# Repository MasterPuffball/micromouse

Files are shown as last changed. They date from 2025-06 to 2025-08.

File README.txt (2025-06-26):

Motor mount has been designed to take a future Pololu Ball Caster with 1/2" metal ball. aka Pololu 953 

https://www.pololu.com/product/953/resources
https://www.digikey.com.au/en/products/detail/pololu/953/10449917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

## Lengths
### Wheel to other Wheel: 83.5mm
### Wheel Width: 6mm
### Axel Length: 89.5mm
### Axel Radius: 44.75mm

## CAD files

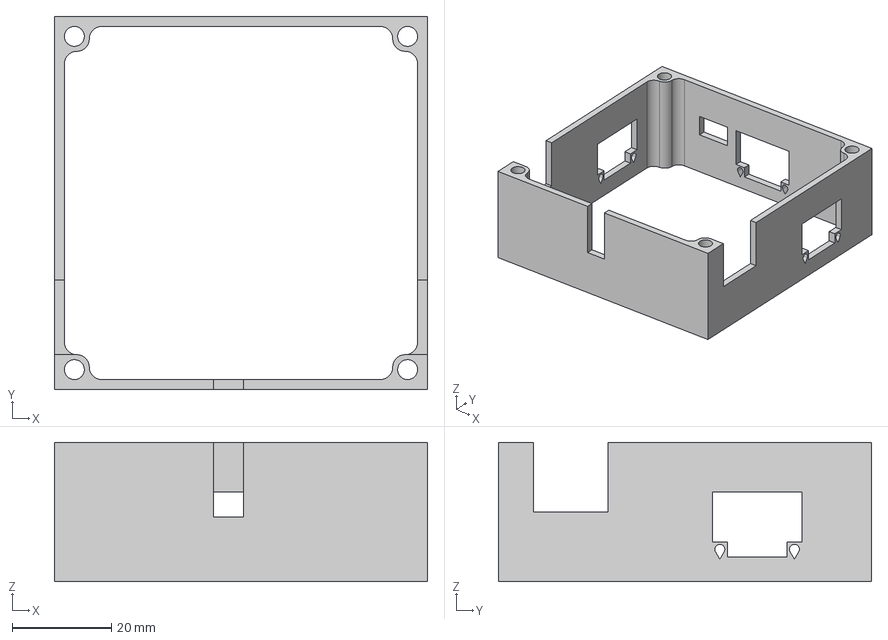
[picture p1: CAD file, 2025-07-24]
mounting/Micromouse Cap.step
75.0 x 75.0 x 28.0 mm

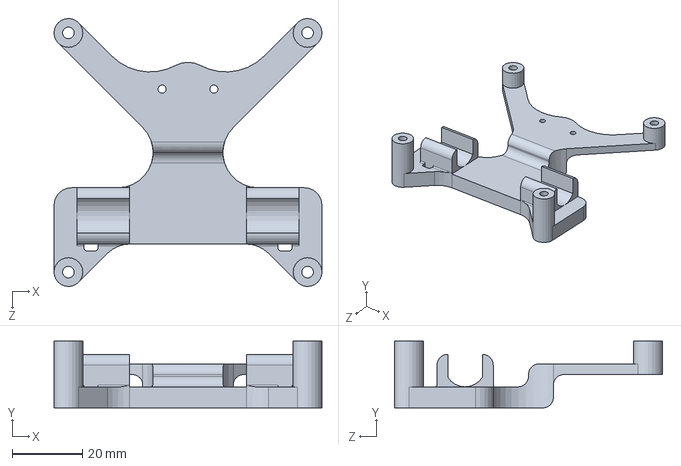
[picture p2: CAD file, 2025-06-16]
mounting/motor_mount.SLDPRT
76.1 x 19.0 x 76.1 mm

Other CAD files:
mounting/Micromouse Cap.SLDPRT
mounting/motor_mount.STL

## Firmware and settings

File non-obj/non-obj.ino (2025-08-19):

#include <SPI.h>
#include <Wire.h>
#include <U8g2lib.h>
#include <Adafruit_GFX.h>

#include "Encoder.hpp"
#include "Motor.hpp"
#include "PIDController.hpp"
#include "Wheel.hpp"
#include "IMU.hpp"
#include "Lidar.hpp"
#include "Map.hpp"
#include "EncoderOdometry.hpp"
#include "Constants.h"
#include "MapRenderer.hpp"

int curTime = 0;
int setCursorFirst = 10;
int setCursorSecond = 7;
float general_speed = 0.45;

struct Robot {
  U8G2_SSD1306_128X64_NONAME_1_HW_I2C display{U8G2_R0, U8X8_PIN_NONE};

  // Maps
  mtrn3100::Map map{};
  mtrn3100::MapRenderer mapRenderer{display, map};

  // Controllers
  static constexpr float KP1 = 2.3;
  static constexpr float KI1 = 0.2;
  static constexpr float KD1 = 0.1;
  mtrn3100::PIDController left_controller{KP1, KI1, KD1};

  static constexpr float KP2 = 2.3;
  static constexpr float KI2 = 0.2;
  static constexpr float KD2 = 0.1;
  mtrn3100::PIDController right_controller{KP2, KI2, KD2};

  // Encoder direction controller
  static constexpr float KP3 = 1.5;
  static constexpr float KI3 = 0.1;
  static constexpr float KD3 = 0.1;
  mtrn3100::PIDController diff_controller{KP3, KI3, KD3};

  // True direction controller
  static constexpr float KP4 = 2.3;
  static constexpr float KI4 = 0.8;
  static constexpr float KD4 = 0.08;
  mtrn3100::PIDController direction_controller{KP4, KI4, KD4, true};

  // Distance Controller
  static constexpr float KP5 = 1.5;
  static constexpr float KI5 = 0.3;
  static constexpr float KD5 = 0.1;
  mtrn3100::PIDController distance_controller{KP5, KI5, KD5};

  // Motors
  static constexpr int MOT2PWM = 9;
  static constexpr int MOT2DIR = 10;
  static constexpr int MOT1PWM = 11;
  static constexpr int MOT1DIR = 12;
  mtrn3100::Motor left_motor{MOT1PWM, MOT1DIR};
  mtrn3100::Motor right_motor{MOT2PWM, MOT2DIR};

  // Encoders
  static constexpr int MOT1ENCA = 2; // PIN 2 is an interupt
  static constexpr int MOT2ENCA = 3;
  static constexpr int MOT1ENCB = 7; // PIN 7 is an interupt
  static constexpr int MOT2ENCB = 8;
  mtrn3100::Encoder left_encoder{MOT1ENCA, MOT1ENCB, 0};
  mtrn3100::Encoder right_encoder{MOT2ENCA, MOT2ENCB, 1};
  mtrn3100::EncoderOdometry odom{&left_encoder, &right_encoder};

  // Wheels
  static constexpr float RIGHT_COEF = 0.91;
  static constexpr float LEFT_COEF = 0.95;
  mtrn3100::Wheel left_wheel{&left_motor, &left_encoder};
  mtrn3100::Wheel right_wheel{&right_motor, &right_encoder};

  // IMU
  mtrn3100::IMU imu{};

  // Lidars
  static constexpr int leftSensorPin = A0;
  static constexpr int frontSensorPin = A1;
  static constexpr int rightSensorPin = A2;
  static constexpr int leftSensorAddress = 0x54;
  static constexpr int frontSensorAddress = 0x56;
  static constexpr int rightSensorAddress = 0x58;
  mtrn3100::Lidar left_lidar{leftSensorPin, leftSensorAddress};
  mtrn3100::Lidar front_lidar{frontSensorPin, frontSensorAddress};
  mtrn3100::Lidar right_lidar{rightSensorPin, rightSensorAddress};

  int robotX = STARTING_X;
  int robotY = STARTING_Y;
  int robotOrientation = STARTING_ORIENTATION;

  Robot() {
  }

  void begin() {
    Serial.println("Beginning Robot");

    initScreen();
    Serial.println("Display Setup Complete");
    drawString("Display Setup Complete");

    delay(50);
  
    imu.begin();
    Serial.println("IMU Setup Complete");
    drawString("IMU Setup Complete");

    odom.begin();

    delay(50);

    initWheels();
    Serial.println("Wheel Setup Complete");
    drawString("Wheel Setup Complete");
        
    delay(50);
    Serial.println("Finished Setup");
    drawString("Finished Setup");
  }
  
  void loop() {
    // moveForwardOneCell();
    
    // display.firstPage();
    // do {
    //   mapRenderer.drawCompletion();
    // } while (display.nextPage());

    exploreMap();
    mapRenderer.drawMap();
	  while (true) {}

    // turnToAngle(0,0.5);
    // maintainDistance(100, 0.5); 
    // turnLeft90(); 
    // executeMovementString("frflflfrf");
    // executeMovement('l');
    // turnToAngle(90,0.4);
    // maintainDistance(100, 0.5);
    // direction_controller.tune(KP4, KI4, i);
    // Serial.println(imu.getDirection());
    // getLeftDist();
    // getFrontDist();
    // getRightDist();
    // turnRight90();
    // testPrintLines();
    
    // drawTelemetry(direction_controller);
    // executeMovementString("lfrfflfr");
    // executeMovementString("ffllfrfr");
    // turnToAngle(-90, 0.3);
    // executeMovementString("r");

  }

  void initScreen() {
    display.begin();
    display.clearBuffer(); // Clear the internal memory
    display.setFont(u8g2_font_4x6_tr); // Choose a suitable font
    display.setCursor(setCursorFirst, setCursorSecond);
    display.print("Staring!!!"); // Write a string to the display
    display.sendBuffer(); // Transfer internal memory to the display
  }

  void initWheels() {
    left_motor.flip();
    // right_motor.flip();
    // left_encoder.flip();
    right_encoder.flip();
  }

  void drawTelemetry(mtrn3100::PIDController controller) {
    display.firstPage();
    do {
      int lineHeight = 6; // 4px font + ~2px spacing
      int startY = 6;     // top margin

      drawTextValueLine("IMU:",        imu.getDirection(),         0, startY + lineHeight * 0);
      // drawTextValueLine("Error:",      controller.getError(),      0, startY + lineHeight * 1);
      // drawTextValueLine("Derivative:", controller.getDerivative(), 0, startY + lineHeight * 2);
      // drawTextValueLine("Integral:",   controller.getIntegral(),   0, startY + lineHeight * 3);
      drawTextValueLine("Left:",      left_lidar.get_dist(),      0, startY + lineHeight * 1);
      drawTextValueLine("Forward:", front_lidar.get_dist(), 0, startY + lineHeight * 2);
      drawTextValueLine("Right:",   right_lidar.get_dist(),   0, startY + lineHeight * 3);
      drawTextValueLine("Target:",     controller.getTarget(),     0, startY + lineHeight * 4);
      drawTextValueLine("Zero:",       controller.getZero(),       0, startY + lineHeight * 5);
      drawTextValueLine("Odom θ:",     odom.getTheta(),            0, startY + lineHeight * 6);

    } while (display.nextPage());
  }

  void drawTextValueLine(const char* message, float num, int x, int y) {
    display.setCursor(x, y);
    display.print(message);
    drawFloatNoClear(num, x + 64, y);
  }

  void drawStringNoClear(const char* message, int x, int y) {
    display.setCursor(x, y);
    display.print(message);
  }

  void drawFloatNoClear(float num, int x, int y) {
    char buf[16];
    dtostrf(num, 0, 1, buf);
    drawStringNoClear(buf, x, y);
  }

  void drawFloat(float num, const int x = setCursorFirst, const int y = setCursorSecond) {
    char buf[16];
    dtostrf(num, 0, 1, buf);
    drawString(buf, x, y);
  }

  void drawString(const char* message, const int x = setCursorFirst, const int y = setCursorSecond) {
    display.clearBuffer(); // Clear the internal memory
    display.firstPage();
    do {
      display.setCursor(x, y); // Set the cursor to the start position
      display.print(message); // Print the message
      display.sendBuffer(); // Transfer internal memory to the display
    } while (display.nextPage());
  }

  void moveForwardDistance(uint16_t dist, float speed) {
    // Set to stay in the current direction
    float startDirection = imu.getDirection();
    direction_controller.zeroAndSetTarget(startDirection, startDirection);

    // Set the wheels to go forward dist
    left_controller.zeroAndSetTarget(left_wheel.getDistanceMoved(), dist);
    right_controller.zeroAndSetTarget(right_wheel.getDistanceMoved(), dist);

    long startTime = millis();

    while (true) {
      // drawTelemetry(left_controller);
      float directionalAdjustment = direction_controller.compute(imu.getDirection());
      float leftSignal = left_controller.compute(left_wheel.getDistanceMoved());
      float rightSignal = right_controller.compute(right_wheel.getDistanceMoved());

      float leftMotorSignal = (constrain(leftSignal, -100, 100) + (directionalAdjustment * DIRECTION_BIAS_STRENGTH)) * speed;
      float rightMotorSignal = (constrain(rightSignal, -100, 100) - (directionalAdjustment * DIRECTION_BIAS_STRENGTH)) * speed;

      left_wheel.setSpeed(leftMotorSignal);
      right_wheel.setSpeed(rightMotorSignal);

      if ((direction_controller.isWithin(10) && left_controller.isWithin(DIST_TOLERANCE) && right_controller.isWithin(DIST_TOLERANCE)) || millis() - startTime > MAX_DURATION) {
        break;
      }
    }

    left_wheel.setSpeed(0);
    right_wheel.setSpeed(0);
  }

  void turnToAngle(float angle, float speed) {
    // Set to move to the target angle
    float startDirection = imu.getDirection();
    direction_controller.zeroAndSetTarget(startDirection, angle);

    float leftZero = left_wheel.getDistanceMoved();
    float rightZero = right_wheel.getDistanceMoved(); 
    diff_controller.zeroAndSetTarget(0, 0);

    long startTime = millis();

    while (true) {
      // drawTelemetry(direction_controller);
      
      float direction = imu.getDirection();
      float directionalAdjustment = direction_controller.compute(direction);
      // Serial.println(direction);
      // drawFloat(direction);

      float leftDiff = left_wheel.getDistanceMoved() - leftZero;
      float rightDiff = -(right_wheel.getDistanceMoved() - rightZero);
      // +ve = left forward /-ve means send left wheel back
      float diffAdjustment = diff_controller.compute(leftDiff - rightDiff);

      float leftMotorSignal = (constrain(directionalAdjustment, -100, 100) + (diffAdjustment * DIFF_BIAS_STRENGTH)) * speed;
      float rightMotorSignal = (constrain(-directionalAdjustment, -100, 100) - (diffAdjustment * DIFF_BIAS_STRENGTH)) * speed;

      left_wheel.setSpeed(leftMotorSignal);
      right_wheel.setSpeed(rightMotorSignal);
      
      if (direction_controller.isWithin(ANGLE_TOLERANCE) || millis() - startTime > MAX_DURATION) {
        break;
      }
    }

    left_wheel.setSpeed(0);
    right_wheel.setSpeed(0);
  }

  void maintainDistance(float distance, float speed) {
    // Set to stay in the current direction
    float startDirection = imu.getDirection();
    direction_controller.zeroAndSetTarget(startDirection, startDirection);

    // Set the wheels to go forward dist
    distance_controller.zeroAndSetTarget(0, distance);

    while (true) {
      float directionalAdjustment = direction_controller.compute(imu.getDirection());
      float distanceAdjustment = distance_controller.compute(front_lidar.get_dist());

      float leftMotorSignal = (constrain(-distanceAdjustment, -100, 100) + (directionalAdjustment * DIRECTION_BIAS_STRENGTH)) * speed;
      float rightMotorSignal = (constrain(-distanceAdjustment, -100, 100) - (directionalAdjustment * DIRECTION_BIAS_STRENGTH)) * speed;

      left_wheel.setSpeed(leftMotorSignal);
      right_wheel.setSpeed(rightMotorSignal);
    }
  }

  // Basically just a DFS (note, must start with back against wall)
  void exploreMap() {
    int cmdNumber = 0;
    char cmds[MAX_MOVEMENTS] = {};
    bool isBacktracking = false;
    bool adjToVisit = true;
    
    // Needs to start with butt against wall
    map.setWall(robotX,robotY,(robotOrientation + 2) % 4);

    while (!(cmdNumber == 0 && !adjToVisit)) {
      visitCurrentCell();
      mapRenderer.drawMap();

      bool visitLeft = shouldTravelTo(-1);
      bool visitForward = shouldTravelTo(0);
      bool visitRight = shouldTravelTo(1);
      adjToVisit = visitLeft || visitForward || visitRight;

      // if not backtracking and shouldn't -> (prioritise left -> right-> forward) go there and save inverse instruction to cmds[cmdNumber] and cmdNumber++ 
      if (!isBacktracking) {
        if (adjToVisit) {
          if (visitLeft) {
            cmds[cmdNumber] = 'r';
            cmdNumber++;
            executeMovement('l');
            cmds[cmdNumber] = 'f';
            executeMovement('f');
          }
          else if (visitForward) {
            cmds[cmdNumber] = 'f';
            executeMovement('f');
          }
          else if (visitRight) {
            cmds[cmdNumber] = 'l';
            cmdNumber++;
            executeMovement('r');
            cmds[cmdNumber] = 'f';
            executeMovement('f');
          }
          cmdNumber++;
        }
        // If "not backtracking" and should (ie dead end) -> turn around, set to is backtracking
        else {
          executeMovement('u');
          isBacktracking = true;
        }
      }
      else {
        // if "backtracking" and shouldn't -> (do one more cmd (only if its a turn), turn around) = turn opposite way to cmd, now not backtracking 
        if (adjToVisit) {
          isBacktracking = false;
          if (cmds[cmdNumber - 1] == 'l') {
            executeMovement('r');
            cmdNumber--;
          }
          else if (cmds[cmdNumber - 1] == 'r') {
            executeMovement('l');
            cmdNumber--;
          }
          else {
            // This is so you dont have to do an unnecessary turn around of turning to go another way at a crossroads
            if (visitLeft) {
              cmds[cmdNumber] = 'l';
              executeMovement('l');
              cmdNumber++;
              cmds[cmdNumber] = 'f';
              executeMovement('f');
            }
            else if (visitForward) {
              cmds[cmdNumber] = 'f';
              executeMovement('f');
            }
            else if (visitRight) {
              cmds[cmdNumber] = 'r';
              cmdNumber++;
              executeMovement('r');
              cmds[cmdNumber] = 'f';
              executeMovement('f');
            }
            cmdNumber++;
          }
        }
        // if "backtracking" and should -> do latest command, subtract cmdNumber 
        else {
          cmdNumber--;
          executeMovement(cmds[cmdNumber]);
        }
      }
    }

    executeMovement('u');
  }

  void drawItems(bool left, bool forward, bool right) {
    float leftF = (left ? 1 : 0);
    float forwardF = (forward ? 1 : 0);
    float rightF = (right ? 1 : 0);

    display.firstPage();
    do {
      int lineHeight = 6; // 4px font + ~2px spacing
      int startY = 6;     // top margin

      drawTextValueLine("Left:",        leftF,         0, startY + lineHeight * 0);
      drawTextValueLine("Forward:",      forwardF,      0, startY + lineHeight * 1);
      drawTextValueLine("Right:", rightF, 0, startY + lineHeight * 2);
      // drawTextValueLine("Integral:",   controller.getIntegral(),   0, startY + lineHeight * 3);
      // drawTextValueLine("Left:",      left_lidar.get_dist(),      0, startY + lineHeight * 1);
      // drawTextValueLine("Forward:", front_lidar.get_dist(), 0, startY + lineHeight * 2);
      // drawTextValueLine("Right:",   right_lidar.get_dist(),   0, startY + lineHeight * 3);
      // drawTextValueLine("Target:",     controller.getTarget(),     0, startY + lineHeight * 4);
      // drawTextValueLine("Zero:",       controller.getZero(),       0, startY + lineHeight * 5);
      // drawTextValueLine("Odom θ:",     odom.getTheta(),            0, startY + lineHeight * 6);

    } while (display.nextPage());
  }

  void scanWalls() {
    if (front_lidar.get_dist() < IS_WALL_DIST) {
      map.setWall(robotX,robotY,robotOrientation);
    }
    if (left_lidar.get_dist() < IS_WALL_DIST) {
      map.setWall(robotX, robotY, (robotOrientation + 3) % 4);
    }
    if (right_lidar.get_dist() < IS_WALL_DIST) {
      map.setWall(robotX, robotY, (robotOrientation + 1) % 4); 
    }
  }

  void visitCurrentCell() {
    scanWalls();
    map.visitCell(robotX, robotY);
  }

  bool shouldTravelTo(int direction) {
    int absoluteDirection = (robotOrientation + (direction + 4)) % 4;
    return !map.cellVisited(robotX, robotY, absoluteDirection) && !map.wallExists(robotX, robotY, absoluteDirection);
  }

  void moveForwardOneCell() {
    moveForwardDistance(180.0, general_speed);
  }

  // Right = positive angle here
  void turnToRelativeAngle(float angle) {
	  turnToAngle(imu.normalizeAngle(imu.getDirection() - angle), general_speed);
  }

  void executeMovementString(char* cmdString) {
    for (int i = 0; cmdString[i] != '\0'; ++i) {
      executeMovement(cmdString[i]);
    }
  }

  void executeMovement(char movement) {
    switch (movement) {
      case 'f': 
        moveForwardOneCell();
        switch (robotOrientation) {
          case UP: robotY -= 1; break;
          case RIGHT: robotX += 1; break;
          case DOWN: robotY += 1; break;
          case LEFT: robotX -= 1; break;
        }
        break;
      case 'l': 
        turnToRelativeAngle(-90); 
        robotOrientation = (robotOrientation + 3) % 4;
        break;
      case 'r': 
        turnToRelativeAngle(90); 
        robotOrientation = (robotOrientation + 1) % 4;
        break;
      case 'u': // U-turn
        turnToRelativeAngle(180);
        robotOrientation = (robotOrientation + 2) % 4;		
        break;
    }
    
    left_wheel.setSpeed(0);
    right_wheel.setSpeed(0);
    delay(50);
  }
};

void setup() {
  Wire.begin();
  Wire.setWireTimeout(1000, true);
  Serial.begin(9600);
  Serial.println("Beginning Setup");
  delay(50);
  Robot robot{};

  constexpr auto a{sizeof(Robot)};
  constexpr auto b{sizeof(mtrn3100::Map)};
  constexpr auto c{sizeof(mtrn3100::PIDController)};

  robot.begin();
  
  delay(100);
  
  while (true) {
    robot.loop();
  }
}

void loop() {}

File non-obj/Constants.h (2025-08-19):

// Constants.h
#ifndef CONSTANTS_H
#define CONSTANTS_H

// Controls Params
#define ANGLE_TOLERANCE 1
#define DIST_TOLERANCE 5
#define DIFF_TOLERANCE 3
#define SLOPE_TOLERANCE 0.02
#define DIRECTION_BIAS_STRENGTH 0.75
#define DIFF_BIAS_STRENGTH 0
#define MAX_DURATION 100000 // in millis

// Wall following constants
#define WALL_DIST 100

// PID 
#define DERIVATIVE_DEADZONE 5
#define INCREMENT_CLAMP 10
#define INTEGRAL_CLAMP 20
#define NUM_STEADY 5
#define STEADY_TOLERANCE 2

// IMU
#define IMU_AVERAGE_AMOUNT 5

// Encoder Odometry
#define WHEEL_DIAMETER 32.4f //In millimeters
#define WHEEL_RADIUS (WHEEL_DIAMETER / 2.0)
#define AXLE_LENGTH 84 //In millimeters
#define TICKS_PER_REV 700
#define WHEEL_CIRCUM (WHEEL_DIAMETER * 3.14159)
#define MM_PER_TICK (WHEEL_CIRCUM / TICKS_PER_REV)
#define ODOM_POLL_TIME 1 //In Milliseconds

// Map Constants
#define MAX_MOVEMENTS 100
#define MAP_HEIGHT 9
#define MAP_LENGTH 9
#define MAX_NODES (MAP_HEIGHT*MAP_LENGTH)
#define UP 0
#define RIGHT 1
#define DOWN 2
#define LEFT 3
#define IS_WALL_DIST 150

// Map Draw Constants
#define CURSOR_START_X 10
#define CURSOR_START_Y 5
#define CELL_SIZE (SCREEN_HEIGHT - (CURSOR_START_Y*2))/MAP_HEIGHT
#define SCREEN_HEIGHT 64
#define SCREEN_LENGTH 128
#define NON_EXISTENT_CELLS 12

// Compact Map Storage Constants
#define NUM_MAP_BITS (MAP_HEIGHT*MAP_LENGTH)
#define NUM_MAP_BYTES ((NUM_MAP_BITS + 7) / 8)

// Robot starting orientation
#define STARTING_ORIENTATION (DOWN)
#define STARTING_X 0
#define STARTING_Y 0




#endif  // CONSTANTS_H

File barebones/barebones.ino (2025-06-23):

#include <SPI.h>
#include <Wire.h>
#include <Adafruit_GFX.h>
#include <Adafruit_SSD1306.h>

#include "Encoder.hpp"
#include "Motor.hpp"
#include "PIDController.hpp"
#include "Wheel.hpp"
#include "Chassis.hpp"

bool screen_initialised = true;
int curTime = 0;

#define SCREEN_WIDTH 128 // OLED display width, in pixels
#define SCREEN_HEIGHT 64 // OLED display height, in pixels
#define OLED_RESET     -1 // Reset pin # (or -1 if sharing Arduino reset pin)
#define SCREEN_ADDRESS 0x3C // I2C adress
Adafruit_SSD1306 display(SCREEN_WIDTH, SCREEN_HEIGHT, &Wire, OLED_RESET);

#define KP1 1.5
#define KI1 1.2
#define KD1 0
#define KP2 1.5
#define KI2 1.2
#define KD2 0
mtrn3100::PIDController left_controller(KP1, KI1, KD1);
mtrn3100::PIDController right_controller(KP2, KI2, KD2);

#define MOT2PWM 9
#define MOT2DIR 10
#define MOT1PWM 11
#define MOT1DIR 12
mtrn3100::Motor left_motor(MOT1PWM, MOT1DIR);
mtrn3100::Motor right_motor(MOT2PWM, MOT2DIR);

#define MOT1ENCA 2 // PIN 2 is an interupt
#define MOT2ENCA 3
#define MOT1ENCB 7 // PIN 7 is an interupt
#define MOT2ENCB 8
mtrn3100::Encoder left_encoder(MOT1ENCA, MOT1ENCB, 0);
mtrn3100::Encoder right_encoder(MOT2ENCA, MOT2ENCB, 1);

// Initialise each wheel
#define RIGHT_COEF 0.91
#define LEFT_COEF 0.95
mtrn3100::Wheel left_wheel(&left_controller, &left_motor, &left_encoder, LEFT_COEF);
mtrn3100::Wheel right_wheel(&right_controller, &right_motor, &right_encoder, RIGHT_COEF);

mtrn3100::Chassis chassis(&left_wheel, &right_wheel);

void initScreen() {
  if(!display.begin(SSD1306_SWITCHCAPVCC, SCREEN_ADDRESS)) {
    Serial.println(F("SSD1306 allocation failed"));
    screen_initialised = false;
  }

  // Clear the buffer
  display.clearDisplay();
}

void drawString(String string) {
  display.clearDisplay();

  display.setTextSize(1);             // Normal 1:1 pixel scale
  display.setTextColor(SSD1306_WHITE);        // Draw white text
  display.setCursor(0,0);             // Start at top-left corner
  display.println(string);

  display.display();
}

void initWheels() {
  left_motor.flip();
  // right_motor.flip();
  // left_encoder.flip();
  right_encoder.flip();
}

void setup() {
  Serial.begin(9600);
  delay(1000);
  initScreen();
  initWheels();
}

void loop() {
  chassis.moveForwardDistance(220);

  while (true) {}
}

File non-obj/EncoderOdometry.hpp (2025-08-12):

#pragma once

#include <Arduino.h>
#include "Constants.h"
#include "Encoder.hpp"

namespace mtrn3100 {
  class EncoderOdometry {
    public:
      EncoderOdometry(mtrn3100::Encoder* leftEncoder, mtrn3100::Encoder* rightEncoder) : leftEncoder(leftEncoder), rightEncoder(rightEncoder) {}

      void begin() {
        reset();
      }

      void reset() {
        leftZero = leftEncoder->getCount();
        rightZero = rightEncoder->getCount();

        x = 0.0f;
        y = 0.0f;
        theta = 0.0f;
        prevLeftTicks = 0;
        prevRightTicks = 0;
        leftTicks = 0;
        rightTicks = 0;
        lastUpdateTime = millis();
      }

      void update() {
        leftTicks = leftEncoder->getCount() - leftZero;
        rightTicks = rightEncoder->getCount() - rightZero;

        long dLeft = leftTicks - prevLeftTicks;
        long dRight = rightTicks - prevRightTicks;

        prevLeftTicks = leftTicks;
        prevRightTicks = rightTicks;

        float dL_mm = dLeft * MM_PER_TICK;
        float dR_mm = dRight * MM_PER_TICK;

        float dCenter = (dL_mm + dR_mm) / 2.0f;
        float dTheta  = (dR_mm - dL_mm) / AXLE_LENGTH;

        theta += dTheta;
        if (theta > PI) {
          theta -= TWO_PI;
        }  
        else if (theta <= -PI) {
          theta += TWO_PI;
        }

        x += dCenter * cos(theta);
        y += dCenter * sin(theta);

        lastUpdateTime = millis();
      }

      float EncoderOdometry::getX() {
        update();
        return x;
      }

      float EncoderOdometry::getY() {
        update();
        return y; 
      }

      float EncoderOdometry::getTheta(){
        update();
        return theta * (180.0f / PI);
      }

      float getLeftSpeedMMs() const {
          static unsigned long lastTime = 0;
          static long lastTicks = 0;

          unsigned long now = millis();
          float dt = (now - lastTime) / 1000.0f;

          if (dt <= 0.0f) return 0.0f;

          long currentTicks = leftTicks;
          float speed = (currentTicks - lastTicks) * MM_PER_TICK / dt;

          lastTicks = currentTicks;
          lastTime = now;

          return speed;
      }

      float getRightSpeedMMs() const {
          static unsigned long lastTime = 0;
          static long lastTicks = 0;

          unsigned long now = millis();
          float dt = (now - lastTime) / 1000.0f;

          if (dt <= 0.0f) return 0.0f;

          long currentTicks = rightTicks;
          float speed = (currentTicks - lastTicks) * MM_PER_TICK / dt;

          lastTicks = currentTicks;
          lastTime = now;

          return speed;
      }

    private:
      float x = 0.0f;
      float y = 0.0f;
      float theta = 0.0f;

      long prevLeftTicks = 0;
      long prevRightTicks = 0;

      long leftTicks = 0;
      long rightTicks = 0;

      long leftZero = 0;
      long rightZero = 0;

      unsigned long lastUpdateTime = 0;

      const mtrn3100::Encoder* leftEncoder;
      const mtrn3100::Encoder* rightEncoder;
  };
} // namespace mtrn3100

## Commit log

2025-06-16 Setup: Created sample directories
2025-06-16 feat: Made mounting bracket for motors and caster wheel (to be bought)
    [motor_mount.SLDPRT, motor_mount.STL]
2025-06-17 feat: Put in some sample driving code
2025-06-19 Node: Somethings wrong with encoders, cant get any data
    [barebones.ino]
2025-06-19 feat: I got basic movement under PID control working. Robot drifts a bit (also need to tune PID)
    [barebones.ino]
2025-06-23 tune: Made tuning fixes
    [barebones.ino]
2025-06-26 feat: Removed the chassis obj to allow more close access to wheel object
2025-06-26 Updated Readme.txt
    To include the lengths of the axel and wheel to wheel radius/length
2025-06-26 feat: Added IMU compatability, its working and reading from the onboard IMU
2025-07-13 Adding lidar sensors
    Added lidar sensor hpp and added comment headers in main file
2025-07-13 Fixed non-obj.ino conflicts
    merge markers were incorrectly added to commit, i have fixed them and removed any duplicates
    [non-obj.ino]
2025-07-15 Added the chainmovement function
2025-07-16 feat: Implemented turning with PID
2025-07-16 fix: got rid of redundant controller
    [non-obj.ino]
2025-07-16 fix: quality of life for IMU reads
    [non-obj.ino]
2025-07-17 Added Wall following to robot
    Wall following works slightly, we need to fix the PID controller
    [non-obj.ino]
2025-07-17 fix: fixed compile issues
    [non-obj.ino]
2025-07-21 fix:tuned turning and driving
    [non-obj.ino]
2025-07-21 Wrote lidar following
2025-07-21 fix: implemented chaining
2025-07-21 Add files via upload
    The top cap for the micromouse
    [Micromouse Cap.SLDPRT]
2025-07-24 uploaded edited version of the cap
    [Micromouse Cap.step]
2025-08-05 First attempt at init fix
    [non-obj.ino]
2025-08-05 Turned Lidar into an object
2025-08-07 fix: screen and imu working tgth
    [non-obj.ino]
2025-08-12 Syntax errors and IMU sampling speed up to max accuracy
    [non-obj.ino]
2025-08-12 implemented encoder odometry
2025-08-18 fixed turning, note Map is too much ram
    [non-obj.ino]
2025-08-18 added in an edge case for exploreing to optimise pathing
2025-08-19 ITS WORKING COMPLETELY (need error zeroing, make random spinning or driving fixed
    [Constants.h, non-obj.ino]
2025-08-19 fixed phantom spins + drives, also removed redundant setFonts
    [non-obj.ino]
2025-08-21 continous and options
    duplicate code just in case
